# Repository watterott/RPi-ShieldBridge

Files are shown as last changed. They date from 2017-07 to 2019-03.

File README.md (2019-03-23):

# RPi-ShieldBridge
Raspberry Pi 1 A/B to Uno Shield Bridge.

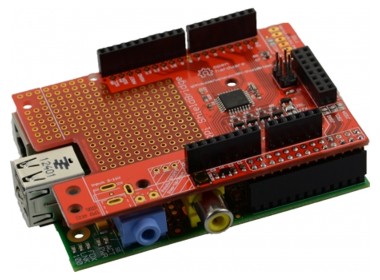
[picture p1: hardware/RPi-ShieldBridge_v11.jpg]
RPi-ShieldBridge


* Microchip ATmega328P with Arduino compatible Bootloader (optiboot)
* Raspberry Pi connected via I2C and UART (to the AVR through level-shifter)
* AVR-Programming via Raspberry Pi possible
* Shield connectors with Uno R3 layout
* Additional 3.3V LDO voltage regulator for Shields
* Prototyping Area
* Open-Source and released under the [Creative Commons Attribution Share-Alike License](https://creativecommons.org/licenses/by-sa/4.0/).
* **[Documentation on learn.watterott.com](https://learn.watterott.com)**

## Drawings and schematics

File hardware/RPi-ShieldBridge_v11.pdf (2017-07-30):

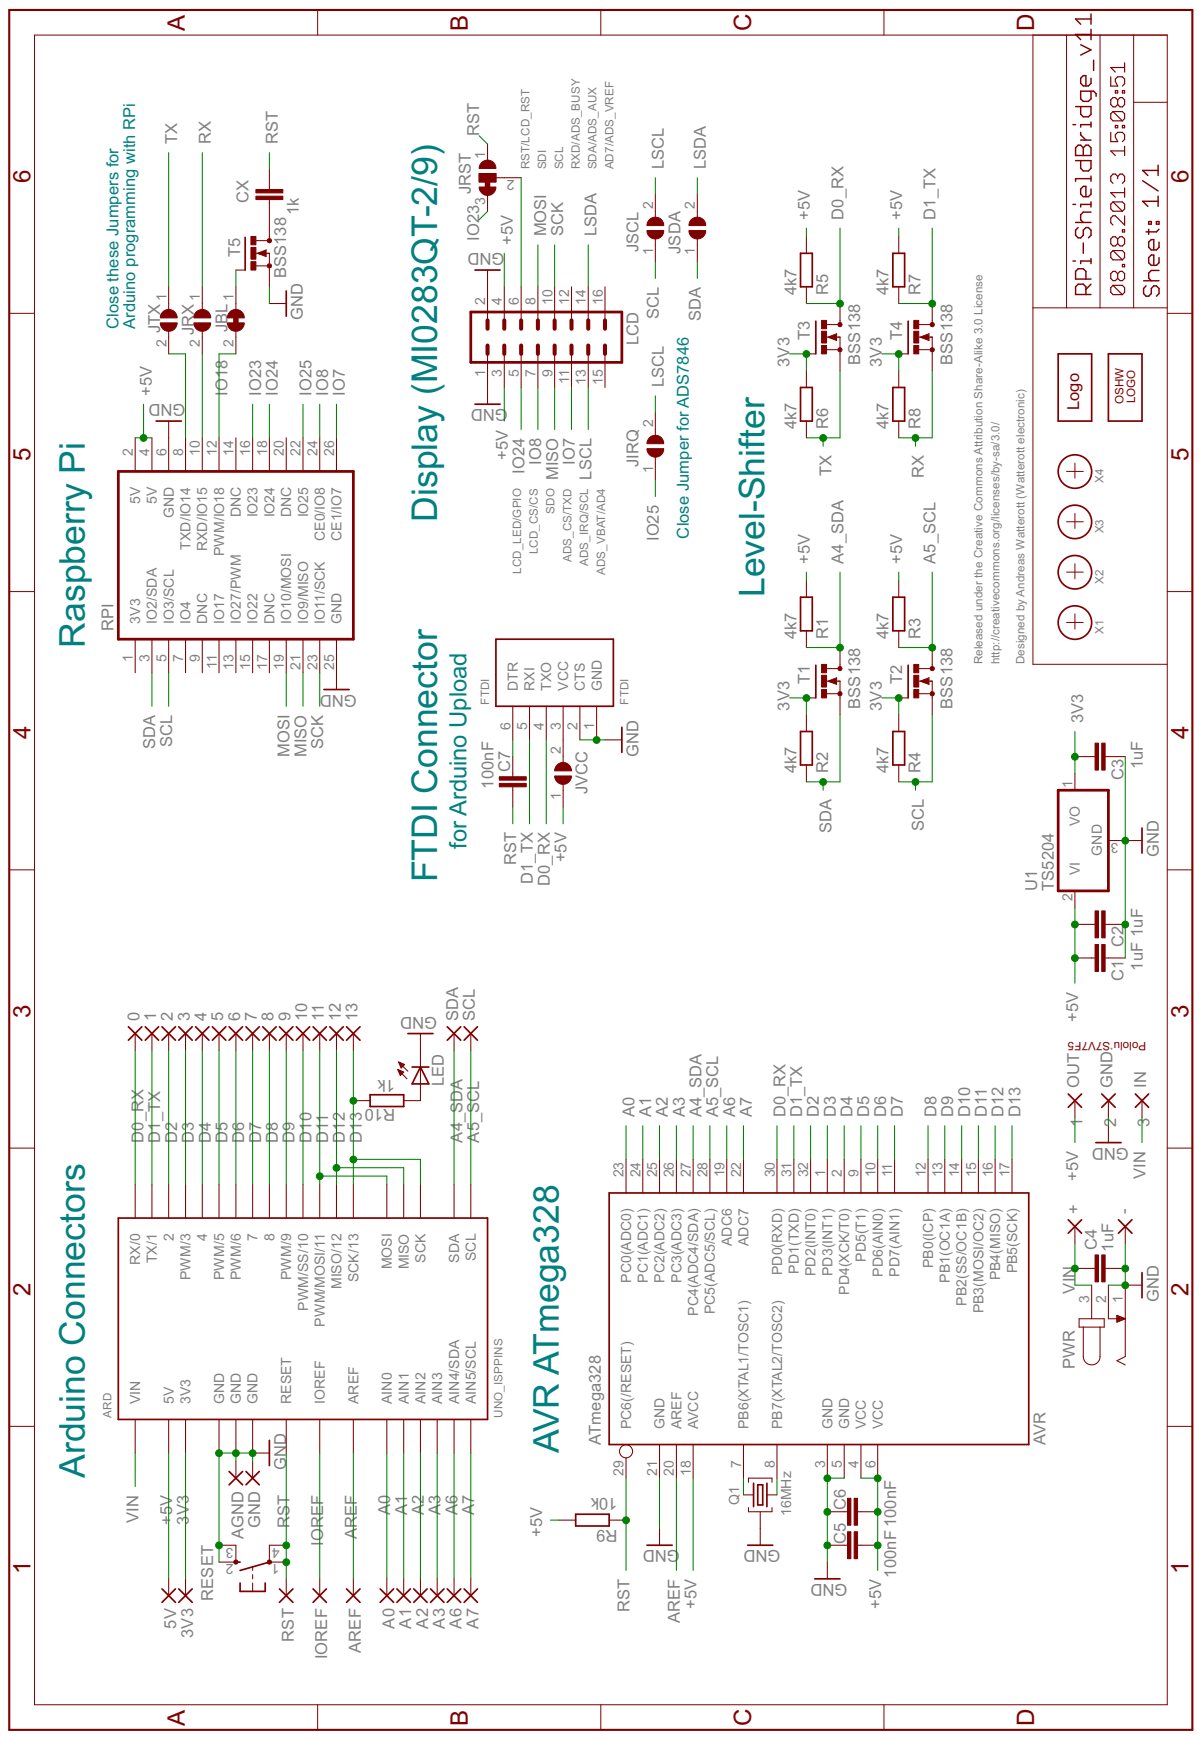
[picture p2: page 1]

Arduino programming with RPi

Close these Jumpers for

Released under the Creative Commons Attribution Share-Alike 3.0 License

Designed by Andreas Watterott (Watterott electronic)

http://creativecommons.org/licenses/by-sa/3.0/

PB4(MISO) 16 PB3(MOSI/OC2) 15 PB2(SS/OC1B) 14 PB1(OC1A) 13 PB0(ICP) 12

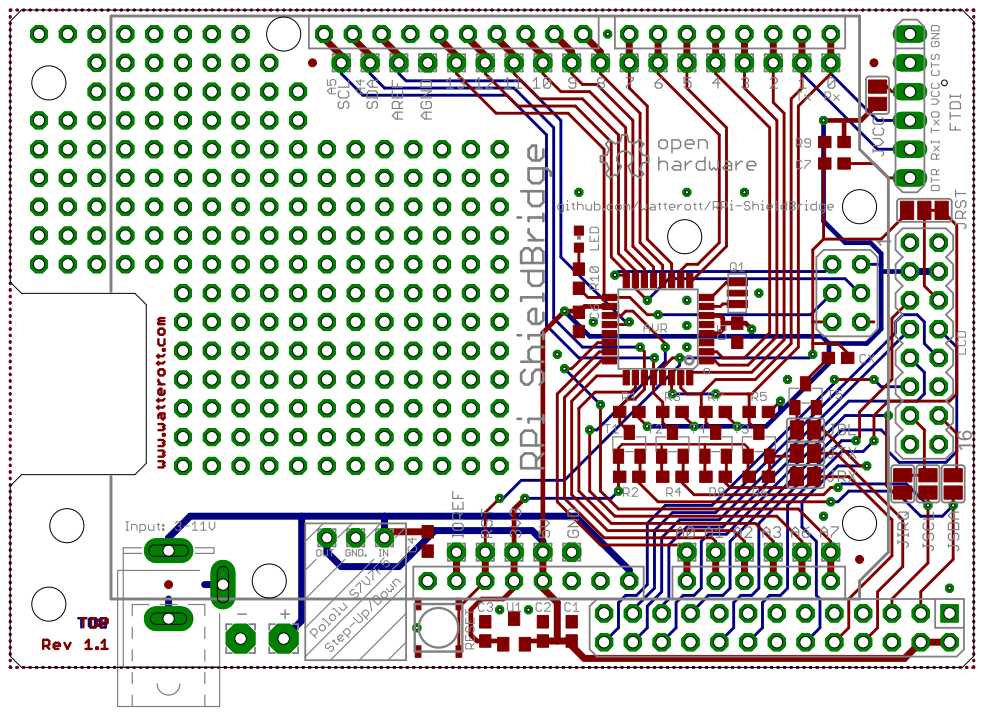
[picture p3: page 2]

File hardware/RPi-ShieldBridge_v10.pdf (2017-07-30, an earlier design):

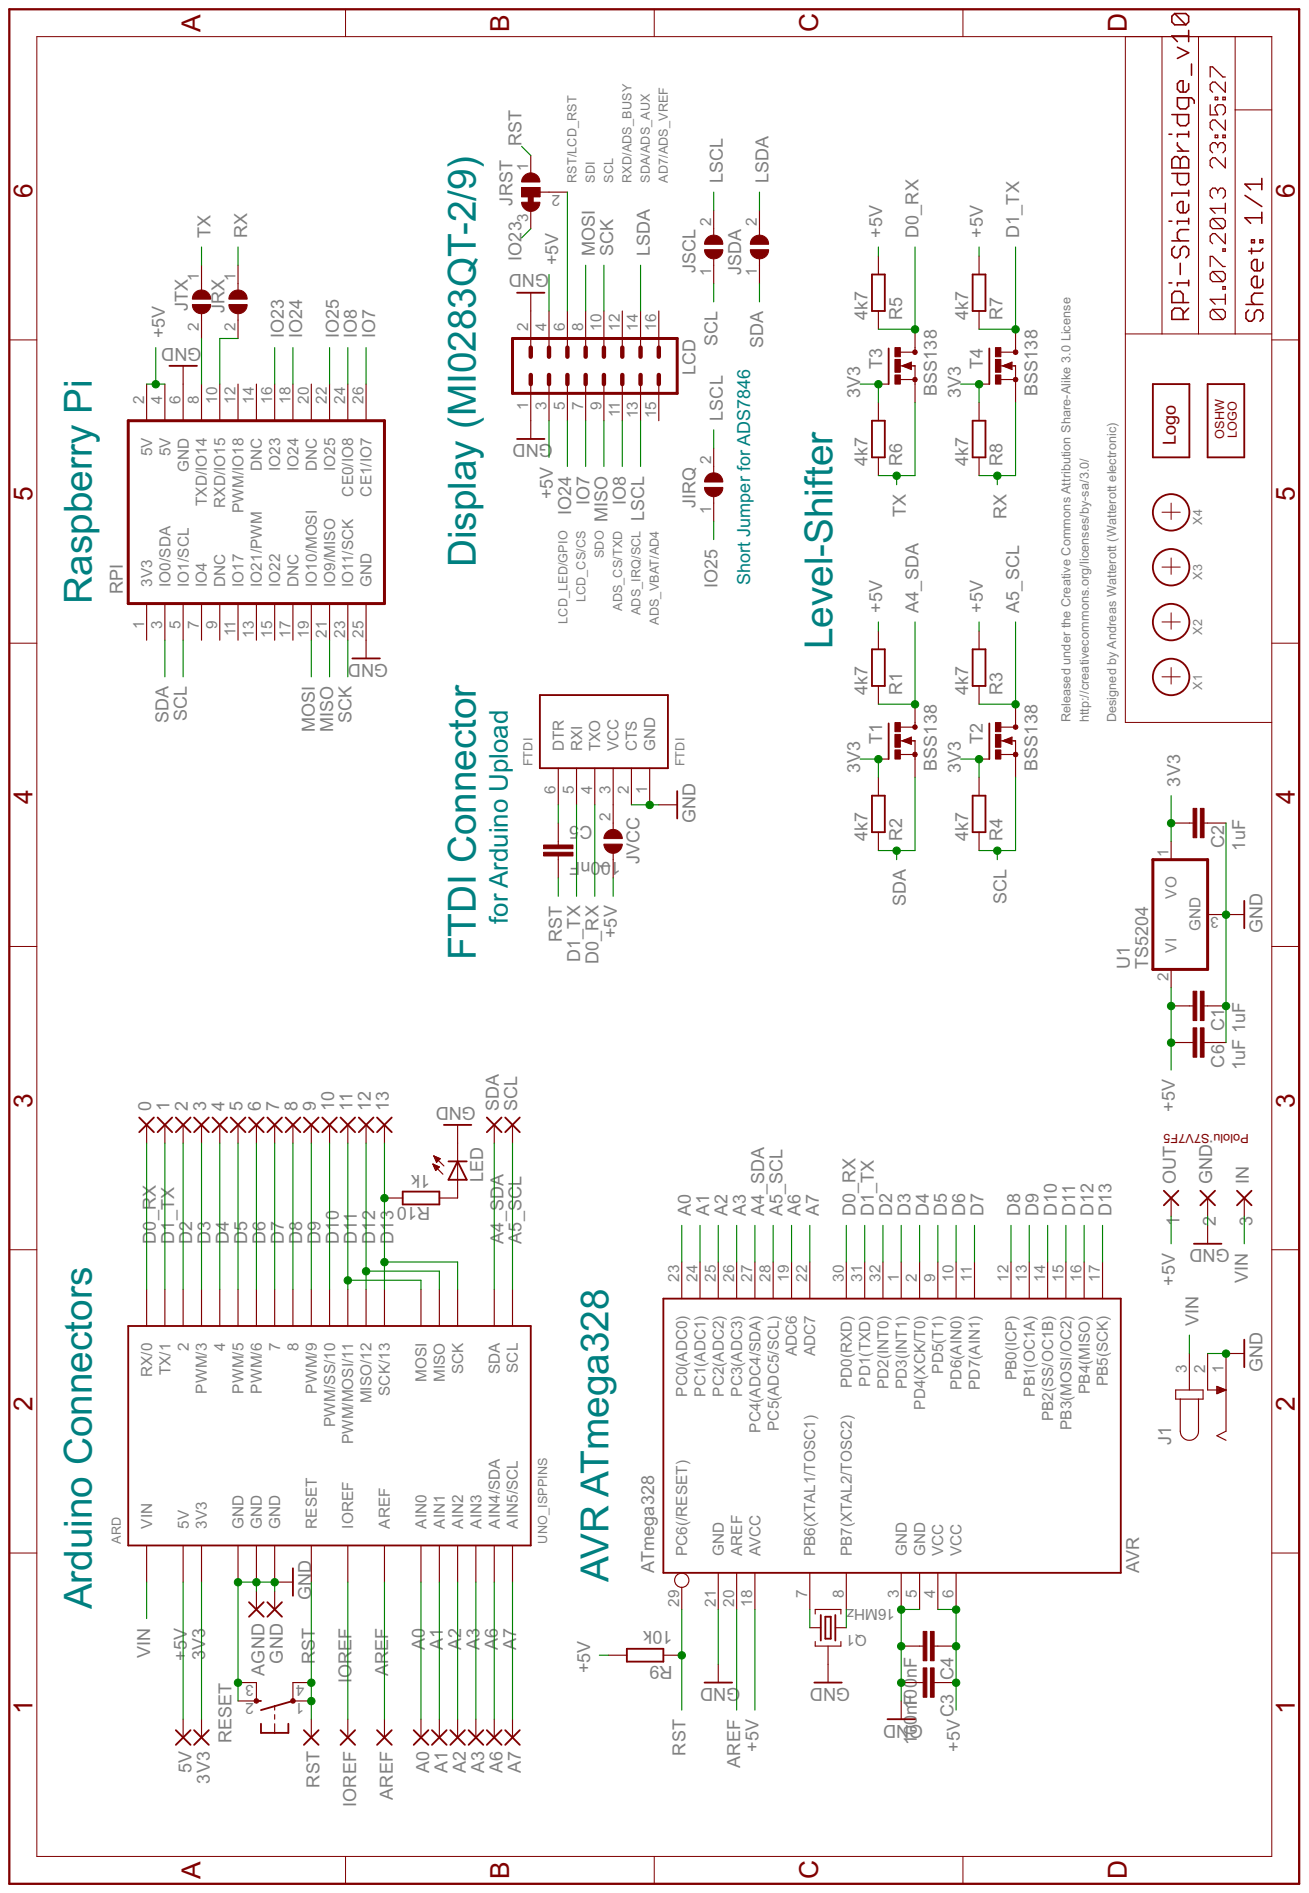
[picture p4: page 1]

Released under the Creative Commons Attribution Share-Alike 3.0 License

http://creativecommons.org/licenses/by-sa/3.0/ Designed by Andreas Watterott (Watterott electronic)

PB4(MISO) 16 PB3(MOSI/OC2) 15 PB2(SS/OC1B) 14 PB1(OC1A) 13 PB0(ICP) 12 PD7(AIN1) 11 PD6(AIN0) 10 PD5(T1) 9 PD4(XCK/T0) 2 PD3(INT1) 1 PD2(INT0) 32 PD1(TXD) 31 PD0(RXD) 30 ADC7

GND GND GND MOSI MISO

8 PWM/9 PWM/SS/10 PWM/MOSI/11 MISO/12 SCK/13 AIN1 AIN2 AIN3 AIN4/SDA

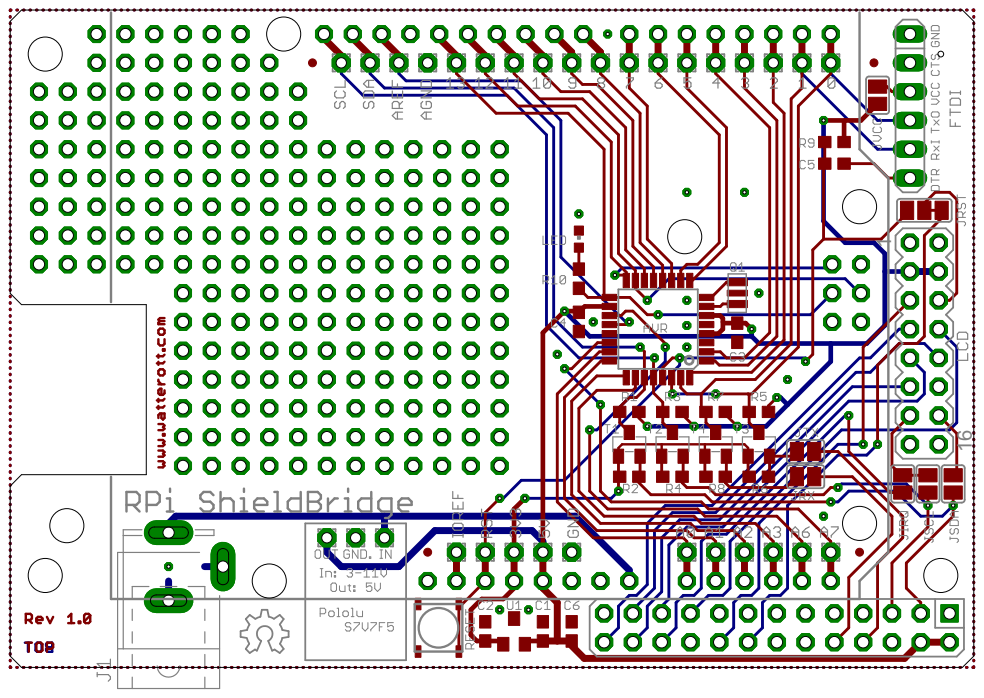
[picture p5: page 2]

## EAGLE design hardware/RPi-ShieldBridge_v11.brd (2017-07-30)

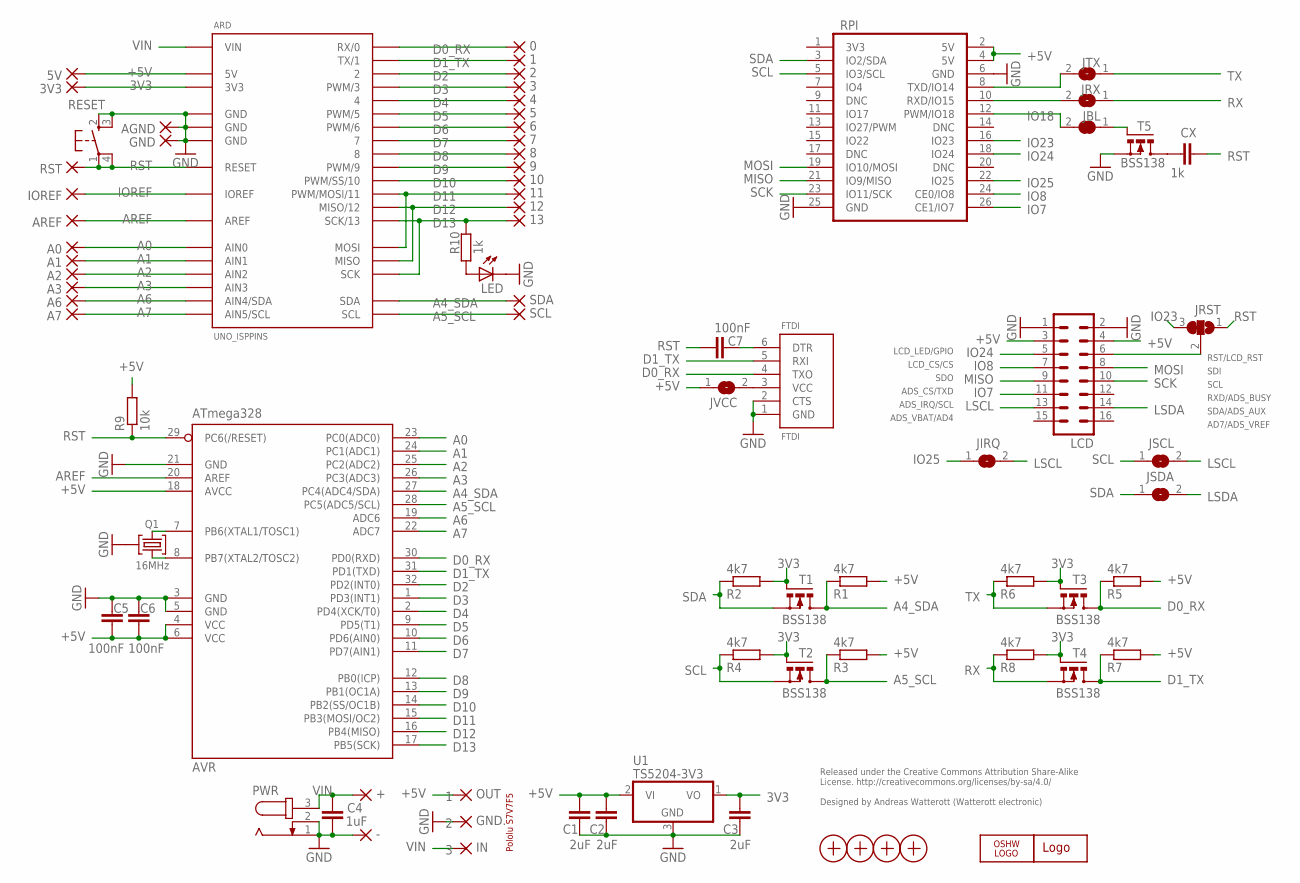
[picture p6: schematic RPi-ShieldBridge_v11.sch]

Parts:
0, 1, 2, 3, 3V3, 4, 5, 5V, 6, 7, 8, 9, 10, 11, 12, 13: WIREPAD1,6/0,9; 1,6/0,9
+: WIREPAD2,54/1,0; 2,54/1,0
-: WIREPAD2,54/1,0; 2,54/1,0
A0, A1, A2, A3, A6, A7: WIREPAD1,6/0,9; 1,6/0,9
AGND: WIREPAD1,6/0,9; 1,6/0,9
ARD: UNO_ISPPINS; UNO_ISP3
AREF: WIREPAD1,6/0,9; 1,6/0,9
AVR: ATmega328; TQFP32-08
C1, C2, C3: 2uF; C0603
C4: 1uF; C0603
C5, C6, C7: 100nF; C0603
CX: 1k; C0603
FTDI: FTDI
GND: WIREPAD1,6/0,9; 1,6/0,9
GND.: 2; 1,6/0,9
IN: 3; 1,6/0,9
IOREF: WIREPAD1,6/0,9; 1,6/0,9
JBL: SJ
JIRQ: SJ
JRST: SJ2W; SJ_2
JRX: SJ
JSCL: SJ
JSDA: SJ
JTX: SJ
JVCC: SJ
LCD: MA08-2
LED: LEDCHIPLED_0603; CHIPLED_0603
LOGO1: OSHW_LOGO_6MILX0150-NT; OSHW_6X150_NOTEXT
OUT: 1; 1,6/0,9
PWR: DC-JACK""; DC-JACK
Q1: 16MHz; SMD_OSC_35X15
R1, R2, R3, R4, R5, R6, R7, R8: 4k7; R0603
R9: 10k; R0603
R10: 1k; R0603
RESET: SW_SMDS; SW_SMD4@1
RPI: RPI
RST: WIREPAD1,6/0,9; 1,6/0,9
SCL: WIREPAD1,6/0,9; 1,6/0,9
SDA: WIREPAD1,6/0,9; 1,6/0,9
T1, T2, T3, T4, T5: BSS138; MICRO3
U1: TS5204-3V3; SOT23
U$1: WE-LOGO
X1, X2, X3, X4: PASSER

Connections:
3V3: 3V3.1, ARD.3V3, C3.1, R2.2, R4.2, R6.2, R8.2, T1.1 (G), T2.1 (G), T3.1 (G), T4.1 (G), U1.1 (VO)
+5V: 5V.1, ARD.5V, AVR.4 (VCC), AVR.6 (VCC), AVR.18 (AVCC), C1.1, C2.1, C5.1, C6.1, JVCC.1, LCD.3, LCD.4, OUT.1, R1.2, R3.2, R5.2, R7.2, R9.2, RPI.2 (5V), RPI.4 (5V), U1.2 (VI)
A0: A0.1, ARD.AIN0, AVR.23 (PC0(ADC0))
A1: A1.1, ARD.AIN1, AVR.24 (PC1(ADC1))
A2: A2.1, ARD.AIN2, AVR.25 (PC2(ADC2))
A3: A3.1, ARD.AIN3, AVR.26 (PC3(ADC3))
A4_SDA: ARD.SDA, AVR.27 (PC4(ADC4/SDA)), R1.1, SDA.1, T1.3 (D)
A5_SCL: ARD.SCL, AVR.28 (PC5(ADC5/SCL)), R3.1, SCL.1, T2.3 (D)
A6: A6.1, ARD.AIN4 (AIN4/SDA), AVR.19 (ADC6)
A7: A7.1, ARD.AIN5 (AIN5/SCL), AVR.22 (ADC7)
AREF: ARD.AREF, AREF.1, AVR.20 (AREF)
D0_RX: 0.1, ARD.0 (RX/0), AVR.30 (PD0(RXD)), FTDI.4 (TXO), R5.1, T3.3 (D)
D1_TX: 1.1, ARD.1 (TX/1), AVR.31 (PD1(TXD)), FTDI.5 (RXI), R7.1, T4.3 (D)
D2: 2.1, ARD.2, AVR.32 (PD2(INT0))
D3: 3.1, ARD.3 (PWM/3), AVR.1 (PD3(INT1))
D4: 4.1, ARD.4, AVR.2 (PD4(XCK/T0))
D5: 5.1, ARD.5 (PWM/5), AVR.9 (PD5(T1))
D6: 6.1, ARD.6 (PWM/6), AVR.10 (PD6(AIN0))
D7: 7.1, ARD.7, AVR.11 (PD7(AIN1))
D8: 8.1, ARD.8, AVR.12 (PB0(ICP))
D9: 9.1, ARD.9 (PWM/9), AVR.13 (PB1(OC1A))
D10: 10.1, ARD.10 (PWM/SS/10), AVR.14 (PB2(SS/OC1B))
D11: 11.1, ARD.11 (PWM/MOSI/11), ARD.MOSI, AVR.15 (PB3(MOSI/OC2))
D12: 12.1, ARD.12 (MISO/12), ARD.MISO, AVR.16 (PB4(MISO))
D13: 13.1, ARD.13 (SCK/13), ARD.SCK, AVR.17 (PB5(SCK)), R10.1
DTR: C7.1, FTDI.6 (DTR)
GND: -.1, AGND.1, ARD.GND@1 (GND), ARD.GND@2 (GND), ARD.GND@3 (GND), AVR.3 (GND), AVR.5 (GND), AVR.21 (GND), C1.2, C2.2, C3.2, C4.2, C5.2, C6.2, FTDI.1 (GND), FTDI.2 (CTS), GND.1, GND..1, LCD.1, LCD.2, LED.C, PWR.1, PWR.2, Q1.GND, RESET.2 (S), RESET.3 (S1), RPI.6 (GND), RPI.25 (GND), T5.2 (S), U1.3 (GND)
IO7: LCD.11, RPI.26 (CE1/IO7)
IO8: LCD.7, RPI.24 (CE0/IO8)
IO18: JBL.2, RPI.12 (PWM/IO18)
IO23: JRST.3, RPI.16 (IO23)
IO24: LCD.5, RPI.18 (IO24)
IO25: JIRQ.1, RPI.22 (IO25)
IOREF: ARD.IOREF, IOREF.1
LCD_RST: JRST.2, LCD.6
LSCL: JIRQ.2, JSCL.2, LCD.13
LSDA: JSDA.2, LCD.14
MISO: LCD.9, RPI.21 (IO9/MISO)
MOSI: LCD.8, RPI.19 (IO10/MOSI)
unnamed: AVR.8 (PB7(XTAL2/TOSC2)), Q1.2
unnamed: AVR.7 (PB6(XTAL1/TOSC1)), Q1.1
unnamed: CX.1, T5.3 (D)
unnamed: LED.A, R10.2
RPI_RST: JBL.1, T5.1 (G)
RST: ARD.RST (RESET), AVR.29 (PC6(/RESET)), C7.2, CX.2, JRST.1, R9.1, RESET.1, RESET.4 (P1), RST.1
RX: JRX.1, R8.1, T4.2 (S)
RX_IO15: JRX.2, RPI.10 (RXD/IO15)
SCK: LCD.10, RPI.23 (IO11/SCK)
SCL: JSCL.1, R4.1, RPI.5 (IO3/SCL), T2.2 (S)
SDA: JSDA.1, R2.1, RPI.3 (IO2/SDA), T1.2 (S)
TX: JTX.1, R6.1, T3.2 (S)
TX_IO14: JTX.2, RPI.8 (TXD/IO14)
VCC: FTDI.3 (VCC), JVCC.2
VIN: +.1, ARD.VIN, C4.1, IN.1, PWR.3

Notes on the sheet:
LCD_LED/GPIO
LCD_CS/CS
SDO
ADS_CS/TXD
ADS_IRQ/SCL
ADS_VBAT/AD4
AD7/ADS_VREF
SDA/ADS_AUX
RXD/ADS_BUSY
SCL
SDI
RST/LCD_RST
Pololu S7V7F5
Released under the Creative Commons Attribution Share-Alike License. http://creativecommons.org/licenses/by-sa/4.0/ Designed by Andreas Watterott (Watterott electronic)

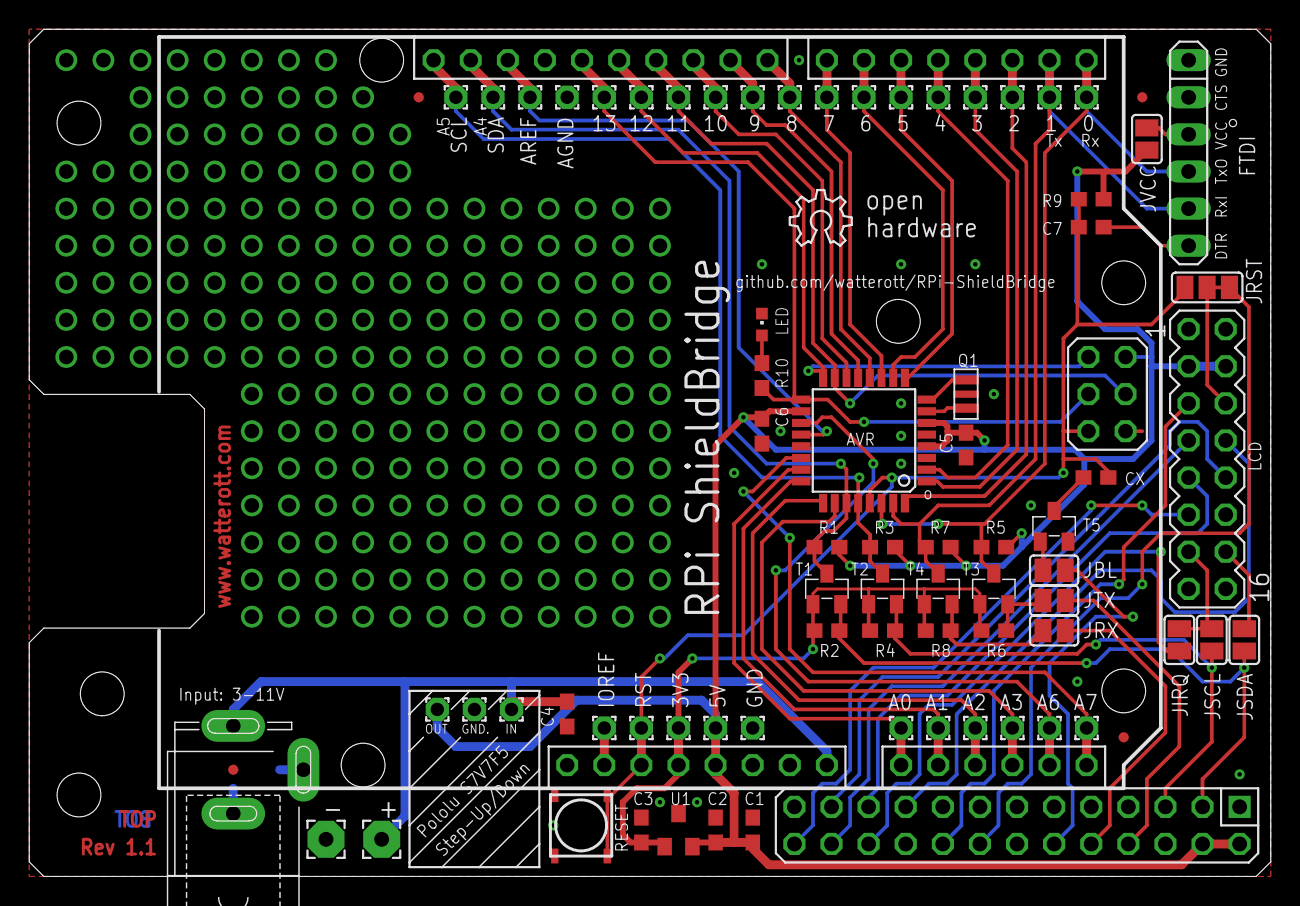
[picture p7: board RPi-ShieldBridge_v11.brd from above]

Board: 2 copper layers, 85.0 x 58.0 mm, 81 parts (1 on the bottom side), 54 nets.

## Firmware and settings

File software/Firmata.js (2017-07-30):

var rpio = require('rpio');
var firmata = require('firmata');

// GPIO18 low -> Arduino reset off
rpio.setOutput(12);
rpio.write(12, rpio.LOW);

// start connection to Arduino
//  USB: /dev/ttyUSB0 or /dev/ttyACM0
//  UART: /dev/ttyAMA0
var board = new firmata.Board('/dev/ttyAMA0', function(err)
{
  if(err)
  {
    console.log(err);
    return;
  }
  console.log('connected');
  board.pinMode(13, board.MODES.OUTPUT);
  // switch on LED
  board.digitalWrite(13, board.HIGH);
  // switch off LED after 3s
  setTimeout(function()
  {
    board.digitalWrite(13, board.LOW);
    process.exit(0);
  }, 3000);
});
